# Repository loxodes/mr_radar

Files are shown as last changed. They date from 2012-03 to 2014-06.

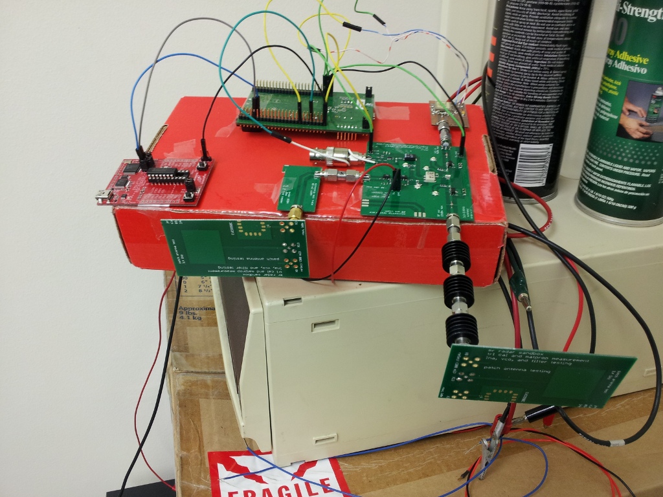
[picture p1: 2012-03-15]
mr_radar.jpg

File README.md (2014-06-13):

**mr_radar**

mr_radar is an in development open hardware frequency modulated continuous wave radar.

It is a radar altimeter for remote control quad-rotor helicopters and UAVs.
Eventually, it may be capable of radar imaging.
One of the goals of this project is to be easily reproducible and inexpensive.

Board layout is done so using KiCad.
Measurements (s-parameters, noise figure measurements) are available in data/ 

All work is under an MIT license, see LICENSE for details. If you have questions, feel free to contact me at jtklein@alaska.edu

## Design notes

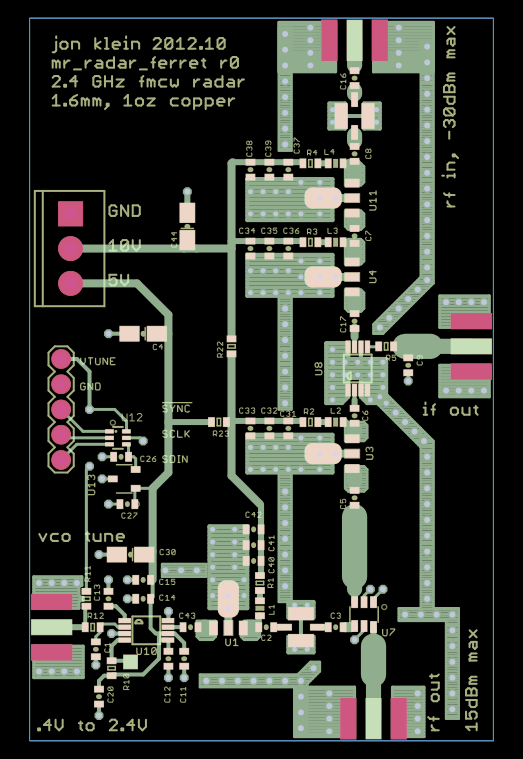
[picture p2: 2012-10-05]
mr_radar_ferret_gerbv.png

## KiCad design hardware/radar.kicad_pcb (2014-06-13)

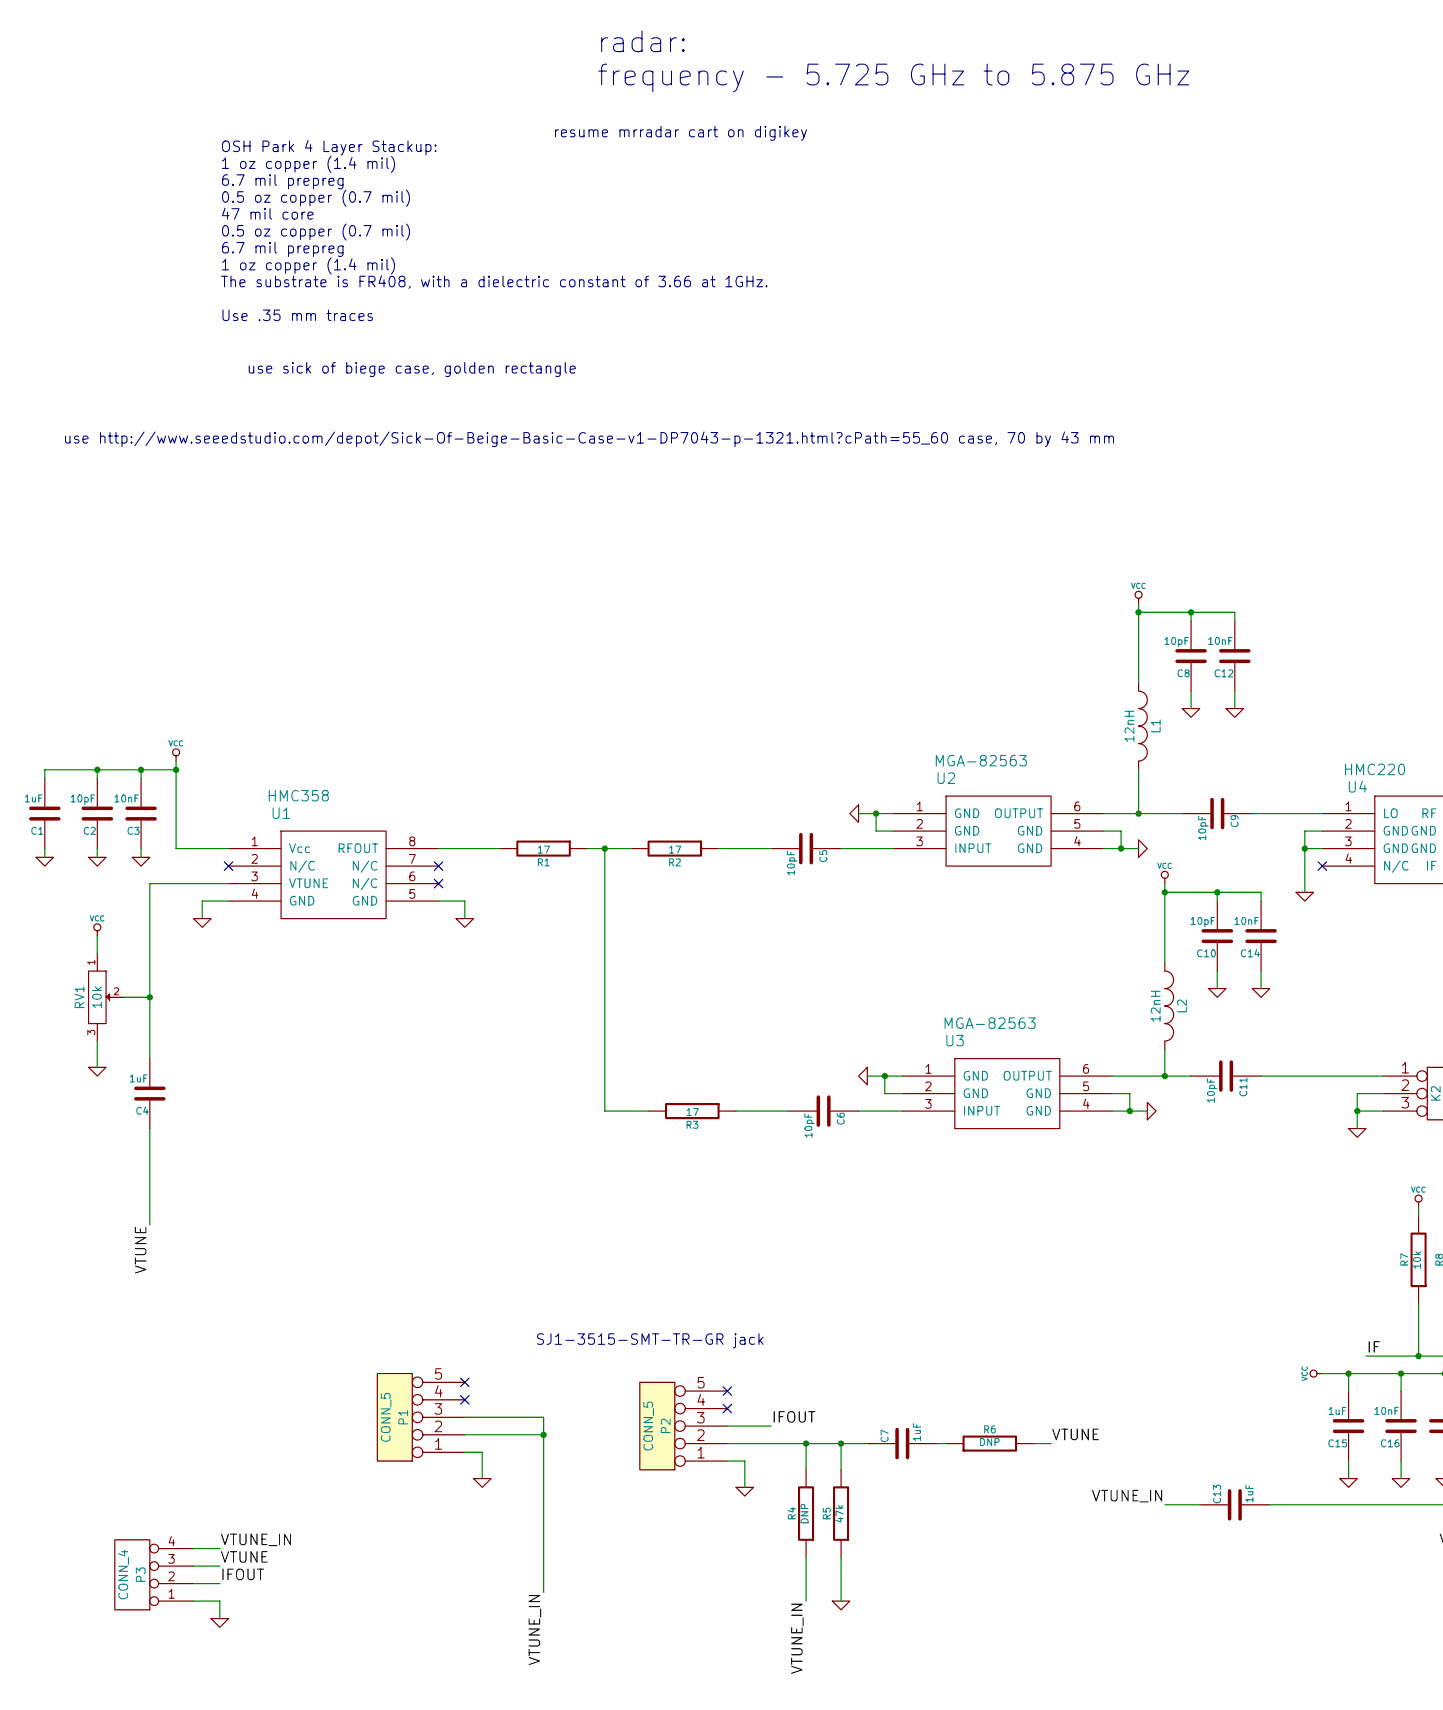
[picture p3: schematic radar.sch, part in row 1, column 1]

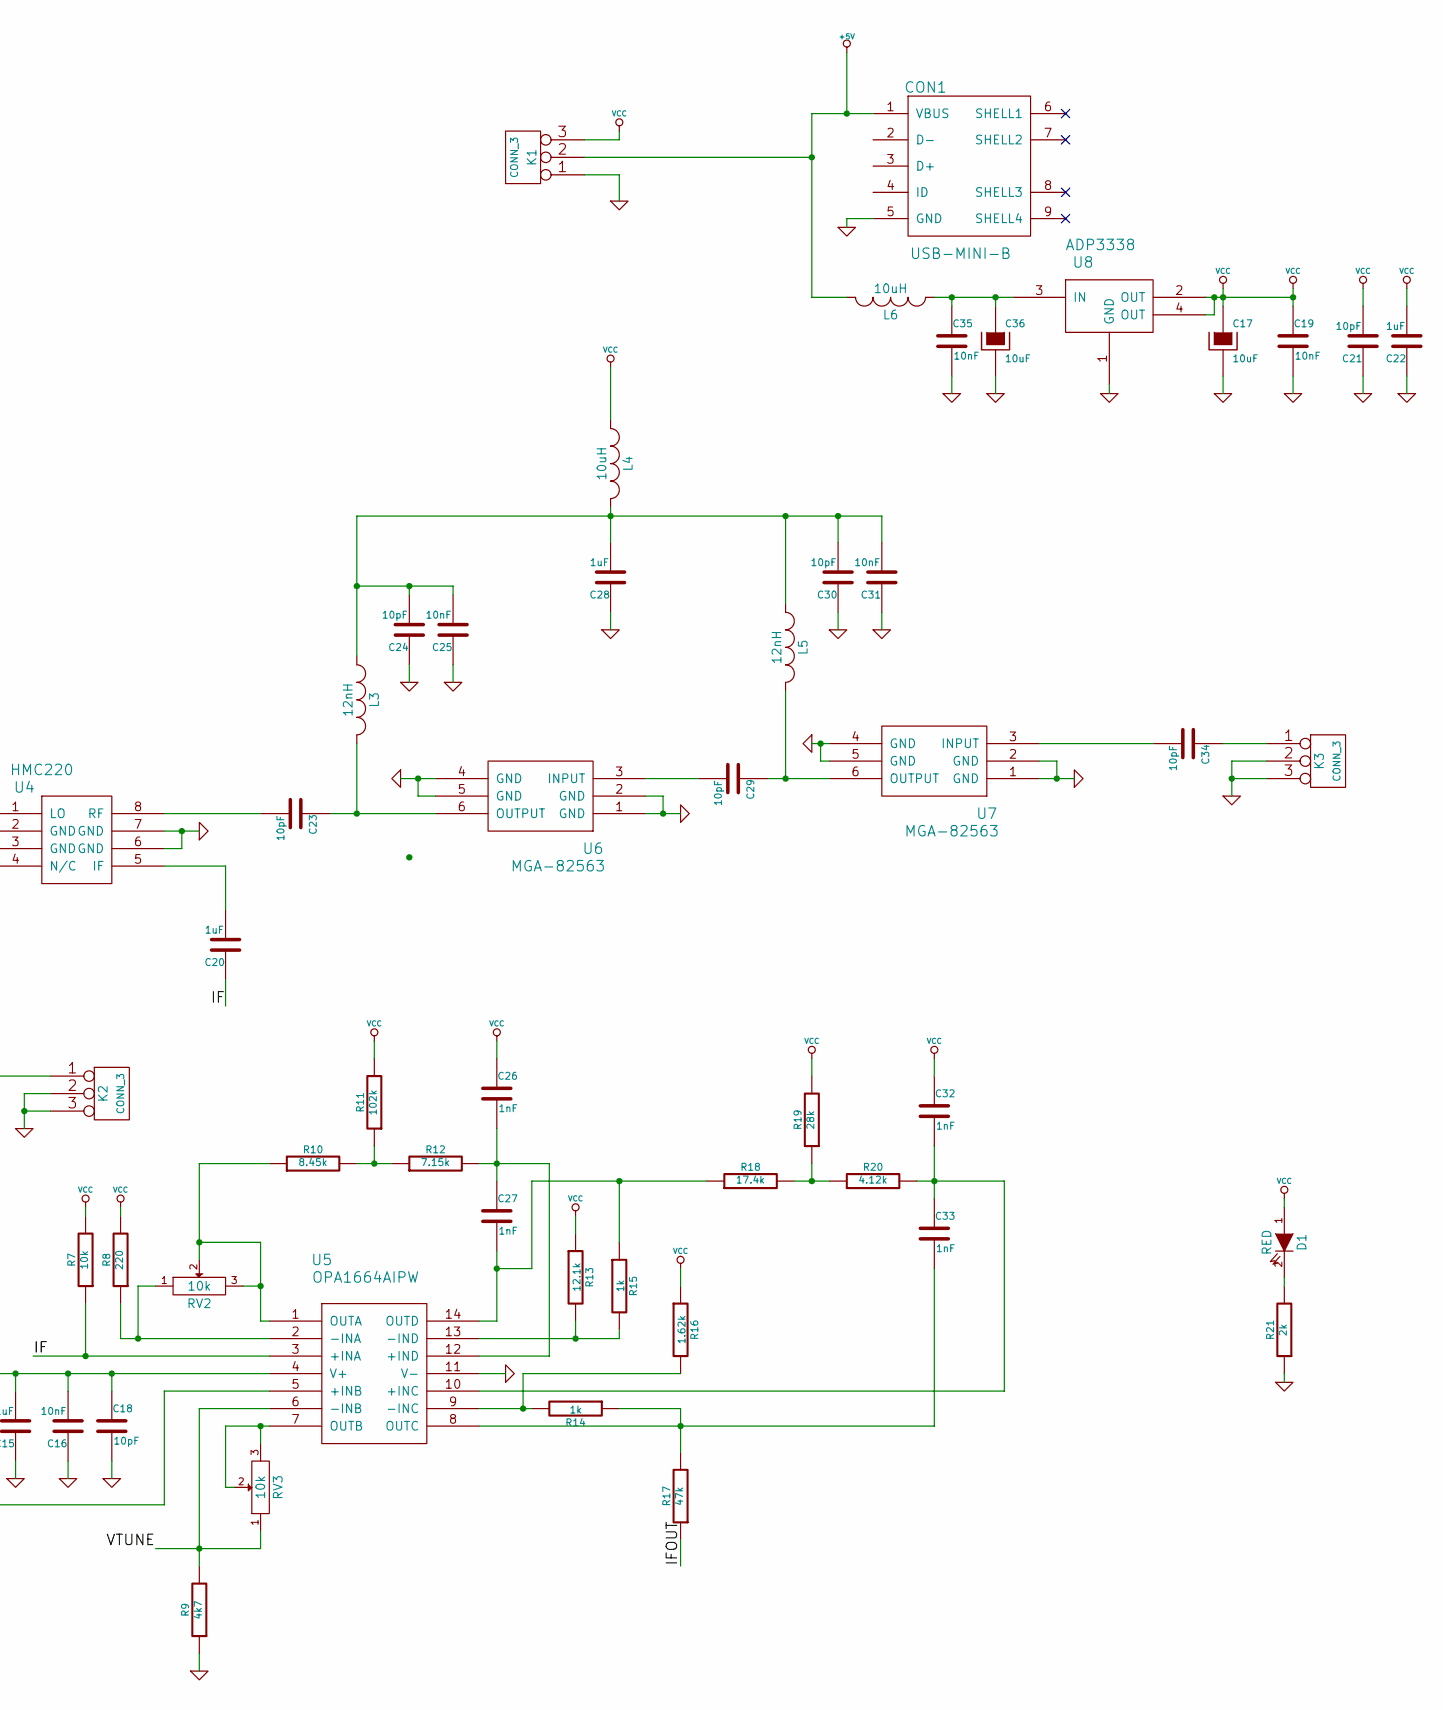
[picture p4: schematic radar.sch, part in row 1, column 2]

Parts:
C1, C4, C7, C13, C15, C20, C22, C28: 1uF; SM0603
C2, C8, C10, C18, C21, C24, C30: 10pF; SM0603
C3, C12, C14, C16, C19, C25, C31, C35: 10nF; SM0603
C5, C6, C9, C11, C23, C29, C34: 10pF; SM0402
C17, C36: 10uF; SM1210
C26, C27, C32, C33: 1nF; SM0603
CON1: USB-MINI-B; USB_MINI_B
D1: RED; LED-0603
K1: CONN_3; PINHEAD1-3
K2, K3: CONN_3; U.FL-COAX
L1, L2, L3, L5: 12nH; SM0402
L4, L6: 10uH; SM1210
P1, P2: CONN_5; SJ1-351X-SMT
P3: CONN_4; SIL-4
R1, R2, R3: 17; SM0402
R4, R6: DNP; SM0603
R5, R17: 47k; SM0603
R7: 10k; SM0603
R8: 220; SM0603
R9: 4k7; SM0603
R10: 8.45k; SM0603
R11: 102k; SM0603
R12: 7.15k; SM0603
R13: 12.1k; SM0603
R14, R15: 1k; SM0603
R16: 1.62k; SM0603
R18: 17.4k; SM0603
R19: 28k; SM0603
R20: 4.12k; SM0603
R21: 2k; SM0603
RV1, RV2, RV3: 10k; Potentiometer_Bourns_3296Z_3-8Zoll_Angular_ScrewFront
U1: HMC358; MSOP-8
U2, U3, U6, U7: MGA-82563; sc70-6
U4: HMC220; MSOP-8
U5: OPA1664AIPW; TSSOP14
U8: ADP3338; SOT223

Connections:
+5V: CON1.1 (VBUS), K1.2 (PM), L6.2
/IF: C20.1, R7.1, U5.3 (+INA)
/IFOUT: P2.3, P3.2, R17.1
/VTUNE: C4.1, P3.3, R6.2, R9.2, RV3.1, U5.6 (-INB)
/VTUNE_IN: C13.1, P1.2, P1.3, P3.4, R4.1
GND: C1.1, C2.1, C3.1, C8.1, C10.1, C12.1, C14.1, C15.1, C16.1, C17.2, C18.2, C19.2, C21.1, C22.1, C24.1, C25.1, C28.1, C30.1, C31.1, C35.2, C36.2, CON1.5 (GND), K1.1, K2.2 (PM), K2.3, K3.2 (PM), K3.3, P1.1, P2.1, P3.1, R5.1, R9.1, R21.1, RV1.3, U1.4 (GND), U1.5 (GND), U2.1 (GND), U2.2 (GND), U2.4 (GND), U2.5 (GND), U3.1 (GND), U3.2 (GND), U3.4 (GND), U3.5 (GND), U4.2 (GND), U4.3 (GND), U4.6 (GND), U4.7 (GND), U5.11 (V-), U6.1 (GND), U6.2 (GND), U6.4 (GND), U6.5 (GND), U7.1 (GND), U7.2 (GND), U7.4 (GND), U7.5 (GND), U8.1 (GND); also elsewhere on the board
unnamed: C4.2, RV1.2, U1.3 (VTUNE)
unnamed: C5.1, U2.3 (INPUT)
unnamed: C5.2, R2.1
unnamed: C6.1, U3.3 (INPUT)
unnamed: C6.2, R3.1
unnamed: C7.1, P2.2, R4.2, R5.2
unnamed: C7.2, R6.1
unnamed: C9.1, U4.1 (LO)
unnamed: C9.2, L1.2, U2.6 (OUTPUT)
unnamed 15: C11.1, K2.1; also elsewhere on the board
unnamed: C11.2, L2.2, U3.6 (OUTPUT)
unnamed: C13.2, U5.5 (+INB)
unnamed: C20.2, U4.5 (IF)
unnamed: C23.1, L3.2, U6.6 (OUTPUT)
unnamed: C23.2, U4.8 (RF)
unnamed: C24.2, C25.2, C28.2, C30.2, C31.2, L3.1, L4.2, L5.1
unnamed: C26.2, C27.1, R12.2, U5.12 (+IND)
unnamed: C27.2, R15.1, R18.1, U5.14 (OUTD)
unnamed: C29.1, L5.2, U7.6 (OUTPUT)
unnamed: C29.2, U6.3 (INPUT)
unnamed: C32.2, C33.1, R20.2, U5.10 (+INC)
unnamed: C33.2, R14.1, R17.2, U5.8 (OUTC)
unnamed 28: C34.1, K3.1; also elsewhere on the board
unnamed: C34.2, U7.3 (INPUT)
unnamed: C35.1, C36.1, L6.1, U8.3 (IN)
unnamed: D1.2 (K), R21.2
unnamed: R1.1, R2.2, R3.2
unnamed: R1.2, U1.8 (RFOUT)
unnamed: R8.1, RV2.1, U5.2 (-INA)
unnamed: R10.1, RV2.2, RV2.3, U5.1 (OUTA)
unnamed: R10.2, R11.1, R12.1
unnamed: R13.2, R15.2, U5.13 (-IND)
unnamed: R14.2, R16.2, U5.9 (-INC)
unnamed: R18.2, R19.1, R20.1
unnamed: RV3.2, RV3.3, U5.7 (OUTB)
VCC: C1.2, C2.2, C3.2, C8.2, C10.2, C12.2, C14.2, C15.2, C16.2, C17.1, C18.1, C19.1, C21.2, C22.2, C26.1, C32.1, D1.1 (A), K1.3, L1.1, L2.1, L4.1, R7.2, R8.2, R11.2, R13.1, R16.1, R19.2, RV1.1, U1.1 (Vcc), U5.4 (V+), U8.2 (OUT), U8.4 (OUT)

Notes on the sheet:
radar: frequency - 5.725 GHz to 5.875 GHz
SJ1-3515-SMT-TR-GR jack
resume mrradar cart on digikey
OSH Park 4 Layer Stackup: 1 oz copper (1.4 mil) 6.7 mil prepreg 0.5 oz copper (0.7 mil) 47 mil core 0.5 oz copper (0.7 mil) 6.7 mil prepreg 1 oz copper (1.4 mil) The substrate is FR408, with a dielectric constant of 3.66 at 1GHz. Use .35 mm traces
use sick of biege case, golden rectangle
use http://www.seeedstudio.com/depot/Sick-Of-Beige-Basic-Case-v1-DP7043-p-1321.html?cPath=55_60 case, 70 by 43 mm

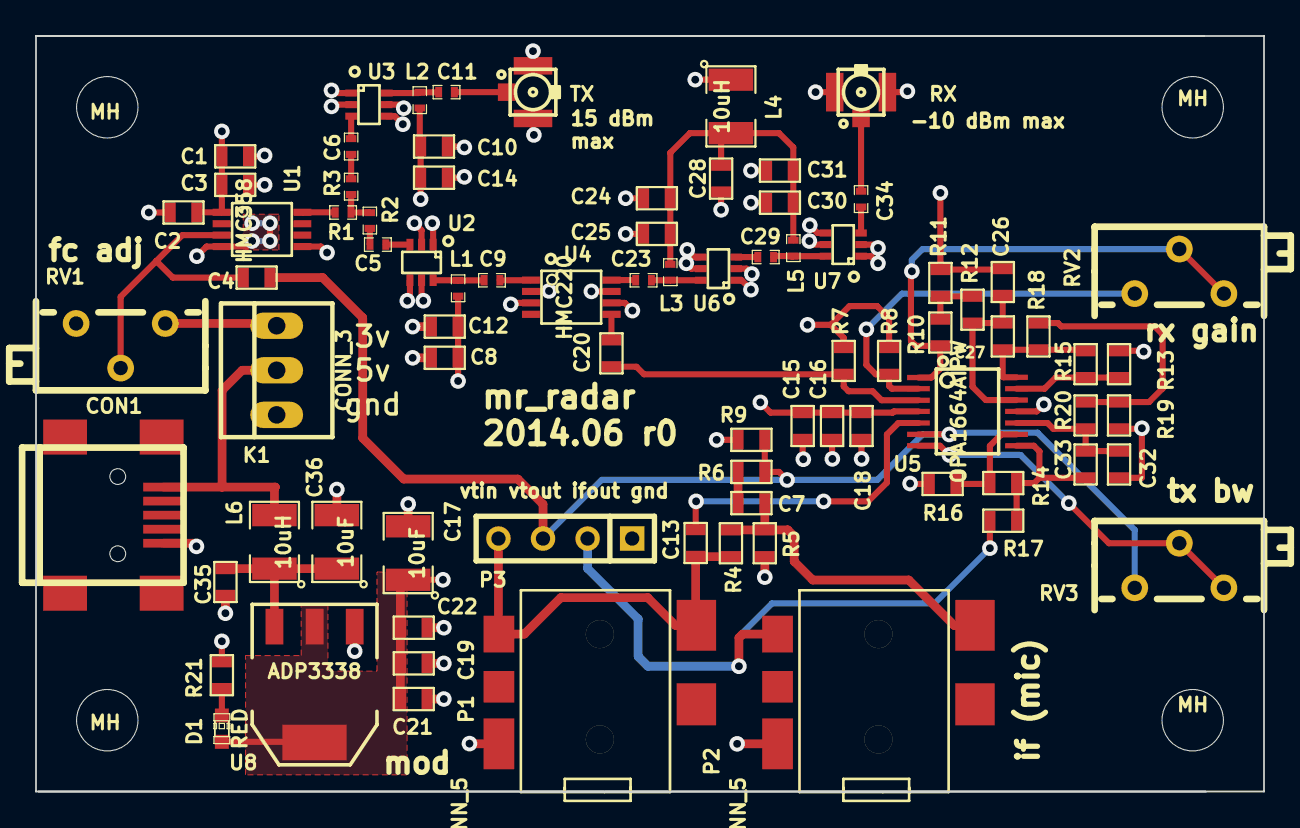
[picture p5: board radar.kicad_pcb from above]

Board: 4 copper layers, 70.0 x 43.1 mm, 86 parts (0 on the bottom side), 42 nets.

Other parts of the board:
MH: MountingHole_3-5mm_RevA_Date21Jun2010; MountingHole_3-5mm
MH#2, MH#3, MH#4: MountingHole_3-5mm_RevA_Date21Jun2010; MountingHole_3-5mm
RX: CONN_3; U.FL-COAX
TX: CONN_3; U.FL-COAX

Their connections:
GND: RX.2, RX.3, TX.2, TX.3; also elsewhere on the board
unnamed 15: TX.1; also elsewhere on the board
unnamed 28: RX.1; also elsewhere on the board

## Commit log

2011-09-15 rough block diagram schematic of mr radar
    [mr_radar.sch]
2011-09-16 added variable gain amplifier to mr_radar library, started amplfier setup. I'll need to make a breakout board for the amp to figure out input/output matching..
    [mr_radar.sch]
2011-09-16 draft of trl cal/amplifier/antenna test board
    [mr_radar_sandbox.brd, mr_radar_sandbox.sch]
2011-09-16 added vco to test board
    [mr_radar_sandbox.brd, mr_radar_sandbox.sch]
2011-09-16 fixed some drc errors: removed overlapping drills and increased to 6mil minimum spacing where possible
    [mr_radar_sandbox.brd]
2011-09-16 fixed soldermask errors, added more via staples
    [mr_radar.brd]
2011-09-17 added r0 gerbers for mr radar sandbox, boards should arrive in a few weeks
    [mr_radar_sandbox.brd, mr_radar_sandbox.sch]
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2011-09-17 finished quad demod schematic, added antialiasing filter
    [mr_radar.brd, mr_radar.sch]
2011-09-18 added headers vtune, I&Q outputs, supply voltage
    [mr_radar.brd, mr_radar.sch]
2011-09-18 started on sandcastle - coupler, antialiasingfilter, baseband amplifier, and balun test board (maybe mixer too)
    [mr_radar_sandcastle.brd, mr_radar_sandcastle.sch]
2011-09-19 removed antialiasing filter, started on layout
    [mr_radar_sandcastle.brd, mr_radar_sandcastle.sch]
2011-09-19 layout of amplifier
    [mr_radar_sandcastle.brd, mr_radar_sandcastle.sch]
2011-09-20 finished component placement and initial layout of sandcastle
    [mr_radar_sandcastle.brd, mr_radar_sandcastle.sch]
2011-09-23 finished sandcastle layout
    [mr_radar_sandcastle.brd, mr_radar_sandcastle.sch]
2011-10-19 fixed mixer filter, added comments
2011-10-27 added frogpond, 31mil routed fr4 edge launch sma connector amplifier and vco test board
    [mr_radar_frogpond.brd, mr_radar_frogpond.sch]
2011-11-16 added mixer/amp/splitter test board
    [mr_radar_platypus.sch]
2011-11-16 added messy broken LO output amplifier
    [mr_radar_platypus.sch]
2011-11-16 added u.FL testpoints on mixer and splitter, placed all components except LO driver amp
    [mr_radar_platypus.brd, mr_radar_platypus.sch]
2011-11-16 placed lo driver
    [mr_radar_platypus.brd, mr_radar_platypus.sch]
2011-11-17 layout of rx and lo amp
    [mr_radar_platypus.brd, mr_radar_platypus.sch]
2011-11-17 partial layout of tx path
    [mr_radar_platypus.brd, mr_radar_platypus.sch]
2011-11-17 finished first pass of layout. proper stiching vias and optimization remain..
    [mr_radar_platypus.brd]
2011-11-17 unfurled layout to larger board
    [mr_radar_platypus.brd, mr_radar_platypus.sch]
2011-11-18 top ground planes finished
    [mr_radar_platypus.brd, mr_radar_platypus.sch]
2011-11-24 added heavily via'ed platypus test board
    [mr_radar_platypus_seeed.brd, mr_radar_platypus_seeed.sch]
2011-12-23 updated layout of radar
    [mr_radar_platypus_seeed.brd]
2012-02-01 mr radar platypus test board ready for manufacturing
    [mr_radar_platypus.sch, mr_radar_platypus_r0.brd, mr_radar_platypus_r0.sch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]
2012-02-01 removed some intermediate files
    [mr_radar.brd, mr_radar.sch, mr_radar_platypus.brd]
2012-02-04 added patch ~3.4GHz patch antenna (to be milled on campus)
    [mr_radar_patch_antenna.brd, mr_radar_patch_antenna.sch]
2012-02-05 added component values to schematic, added silkscreen layer
    [mr_radar_patch_antenna.brd, mr_radar_platypus_r0.brd, mr_radar_platypus_r0.sch]
2012-02-06 increased size of u.fl test point jumpers. attached gerbers of r0, sent for manufacturing
    [mr_radar_platypus_r0.brd, mr_radar_platypus_r0.sch]
2012-02-16 added measured s2p of patch antenna (matches simulation! http://kl1xf.org/1329427704.png), now to optimize it..
2012-03-07 added if amp and antialiasing filter values and LTSpice simulation, changed package sizes for rx amp decoupling capacitors, updated silkscreen with proper supply voltages
    [mr_radar_platypus.brd, mr_radar_platypus.sch]
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2012-03-11 added control of radar samples over serial port
2012-03-12 added bus pirate support to adc_grab (much faster sample uploading..)
2012-03-13 added mr_radar_trolley, voltage regulator/usb to usart/vco driver amplifier board
    [mr_radar_trolley.brd, mr_radar_trolley.sch]
2012-03-13 finished component placement draft on mr_radar_trolley
    [mr_radar_trolley.brd, mr_radar_trolley.sch]
2012-03-13 finished mr_radar_trolley layout
    [mr_radar_trolley.brd]
2012-03-14 fixes to ft232rl layout and schematic, cleanup of silkscreen layer, sent for manufacturing
    [mr_radar_trolley.brd, mr_radar_trolley.sch]
2012-03-20 added pulsed rf source test board
    [mr_radar_pulser.brd, mr_radar_pulser.sch]
2012-03-20 finished silkscreen layer on mr_radar_pulser
    [mr_radar_pulser.brd, mr_radar_pulser.sch]
2012-03-22 added LT5534 to library, mr_radar_pulser ready for manufacturing
    [mr_radar_pulser.brd, mr_radar_pulser.sch]
2012-03-26 added patch antenna (WLP.2450.25.4.A.02) to library, mr_radar_pulser sent for manufacturing
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2012-10-03 started work on mr_radar_ferret, and redesigned FMCW front end for 2.4 GHz with an integrated VCO, DAC, and ADC
    [mr_radar_ferret.brd, mr_radar_ferret.sch]
2012-10-03 component placement complete on ferret, layout partially complete. silkscreen cleanup and amplifier grounds remain
    [mr_radar_ferret.brd, mr_radar_ferret.sch]
2012-10-03 split adc front-end to another board, changed microstrip for 1.6mm thick board
    [mr_radar_ferret.brd, mr_radar_ferret_afe.brd, mr_radar_ferret_afe.sch]
2012-10-04 mr_radar_ferret r0, sent for manufacturing
    [mr_radar_ferret.brd, mr_radar_ferret.sch]
2012-10-26 currently tested ferret r0, fixing a few bugs for the next revision, board layout of ferret now incomplete. isolation is much better than in platypus, but it is still a problem
    [mr_radar_ferret.brd, mr_radar_ferret.sch, mr_radar_ferret_afe.brd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]
2014-06-13 removed abandoned boards, added latest revision
    [mr_radar_ferret.brd, mr_radar_ferret.sch, mr_radar_ferret_afe.brd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]
